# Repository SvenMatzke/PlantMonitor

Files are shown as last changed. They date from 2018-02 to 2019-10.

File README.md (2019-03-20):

# PlantMonitor
Whats the goal an esp sending soil moisture temperature, humidity and light to an source in your network.
The source for now is fully functioning webserver backend and a webfrontend written in react.

# ESP setup:
For all wireing we need wires so always keep in mind you will need those in addition to your chips and power. 

# Catch 
Easy plant monitoring in a few steps. 

# Setup
An Esp32 is the base as a controller for micropython. 
Simply because we have plenty of IO and plenty of power for little money and we can measure the 
Analog in even without resistors! On Esp8266 we would need a voltage between 0-1 V

## Additional Sensor
 - dht22 (AM2302) 
 - BH1750FVI GY-30
 - Soil Moisture Sensor
 
# for Comport
 - Reset Switch/Button

# Hardware (Power supply Part)
For the Power supply part we use simple AA Rechargeable batteries and a step up chip to get our needed 3.3 V
In the future it is planed that the power and sensor part are seperate in design. Because there are multiple solutions for 
powering up an esp and less variants regarding getting the sensor data we want.
  - 2 AA recharable batteries
  - 1 Booster step-up to 3.3 V (4,49 €)
    https://eckstein-shop.de/Pololu-33V-Step-Up-Spannungsregler-U1V10F3
  - battery holder or
  - Romi Battery Contact Set (2 € for 2 sets) 
 
costs without batteries 7€

# First Installation
Install micropython on your esp8266 (instructions in the micropython link below)
A fully functioning esp firmware can be found under the source folder.
This firmware is needed because if you dont precompile the userv.py and some the sensor module for the light sensor Tsl,
your esp will run out of memory and will not work.

# Second step 
Wire your sensors there is a folder wireing for more details or adjust the sensor.py with your own configuration.
Im the source folder is dist folder which will provide several data from the subfolder python and static_index/dist.
You will need to upload all there files, its the backend, and the webfrontend.

# Third step
Fire up your esp8266. When booting on hardreset you will have 300s to configure your
Plantmonitor via Web. Simply connect to the Wlan 'Plantmonitor' PW: 'Plantmonitor' 
and set the features you need like new ssid and password ;-).

# Running and be happy
From here your Esp will go to Deepsleep for a time set by your config. After this time it will wake up store the current 
sensor data and go offline again for your Deepsleep. To get your data either send them directly to another ip on fireup or
press the reset button to go into configuration-mode again. In this mode you are also able to
read all data saved by your esp yet. 
A webfrontend is reachable if you are connected directly under 192.168.1.4 else the ip used in your network.

# From here on out
We will want to pack power supply and apply your wireing and esp into an casing. 
An 3d printer example will be put in 3d casing

# Infos and Greetings
micropython:
https://docs.micropython.org/en/latest/esp8266/esp8266/tutorial/intro.html

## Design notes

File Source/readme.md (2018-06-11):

#link wireing todo

Frontend of Plantmonitor is static website with backend communication to the esp

Intention will be a webpacked javascript framework delivering everything we need even without internet.

we have 4 mb flash drive but there is also micropython and your python source on it.
this results in your webpacked static files should be less then 3 mb.
"""

Booting will just decide which wlan connection we will choose

http://docs.micropython.org/en/latest/esp8266/esp8266/tutorial/network_basics.html
http://docs.micropython.org/en/latest/esp8266/esp8266/tutorial/powerctrl.html

"""

Puts your device to deepsleep for a given time.
Hardware note:
connect gpio16 to reset to be able to deep sleep

"""
This will be the only file which may need to be customised
http://docs.micropython.org/en/latest/esp8266/esp8266/tutorial/dht.html
https://github.com/adafruit/micropython-adafruit-tsl2561/blob/master/docs/tsl2561.rst

"""

we need to but userv.py and the tsl2561 package into the build of the esp firmware because we dont have the memory to do it on the fly

https://pypi.python.org/pypi/tsl2561/3.3

sda=2 scl=14 
adc lower 1 v

unpowering light sensor_connection renders sensor useless so you cant unpower it

when starting server you need little above 9 k memory to run esp
# 

# Building firmware with needed external packages
Build your firmware with modules from from source/externalpackages
Normaly one firmware is checked in with the needed modules, but it is not sure that
this will stay this way. 

# Building Frontend
Step into folder source/static_index and follow the instructions. 

# Software assemble 
The main purpose is to assemble all needed files for one Device to flash.
Needed Software is:
    - builded micropython firmware 
    - builded frontendfiles

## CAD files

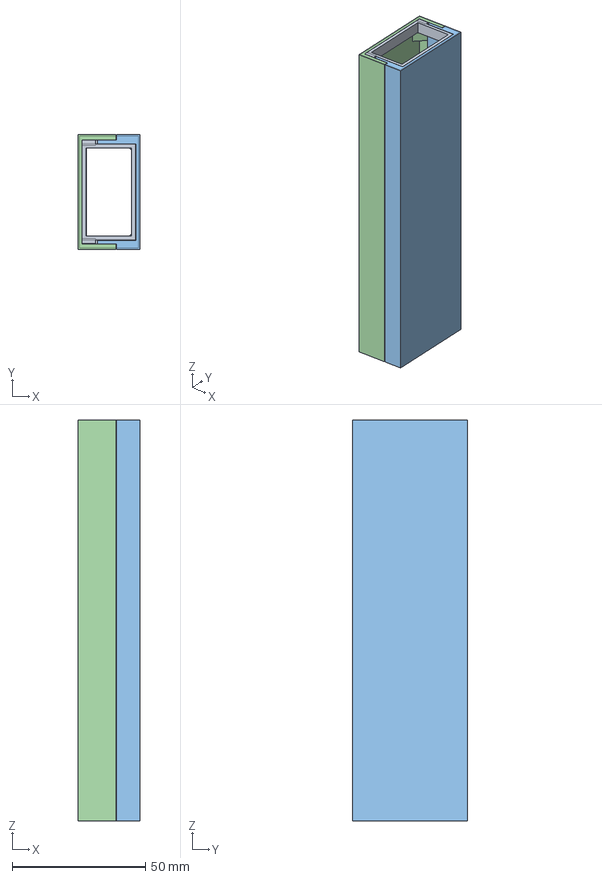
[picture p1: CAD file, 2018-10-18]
Assembly/BaseParts/assembly.FCStd
23.2 x 43.1 x 150.3 mm
BaseLowerSensorMount_01
BaseUpperSensorMount_01
BaseClippedSide_01
BaseClippingSide_01

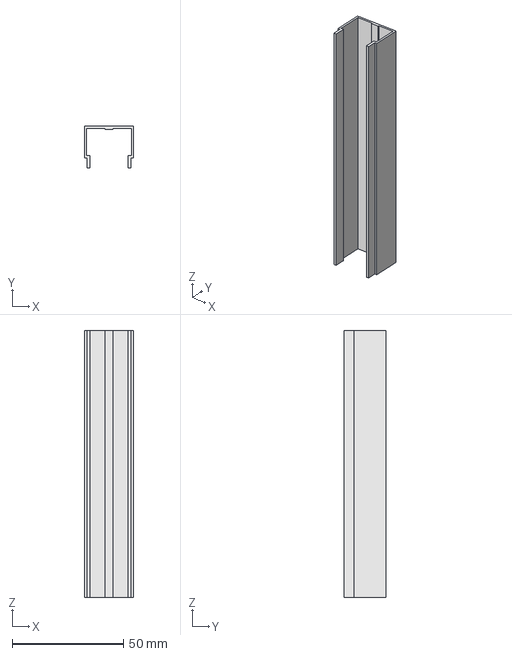
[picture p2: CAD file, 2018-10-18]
Assembly/BaseParts/BaseLeftSide.FCStd
22.0 x 18.7 x 120.0 mm

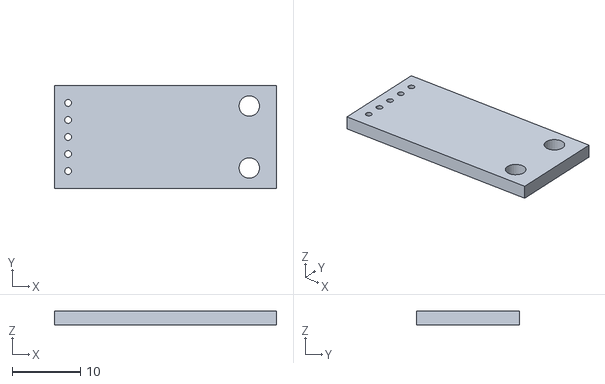
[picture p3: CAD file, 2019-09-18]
Assembly/ElectronicShapes/gy-30.stl
32.6 x 15.1 x 2.00

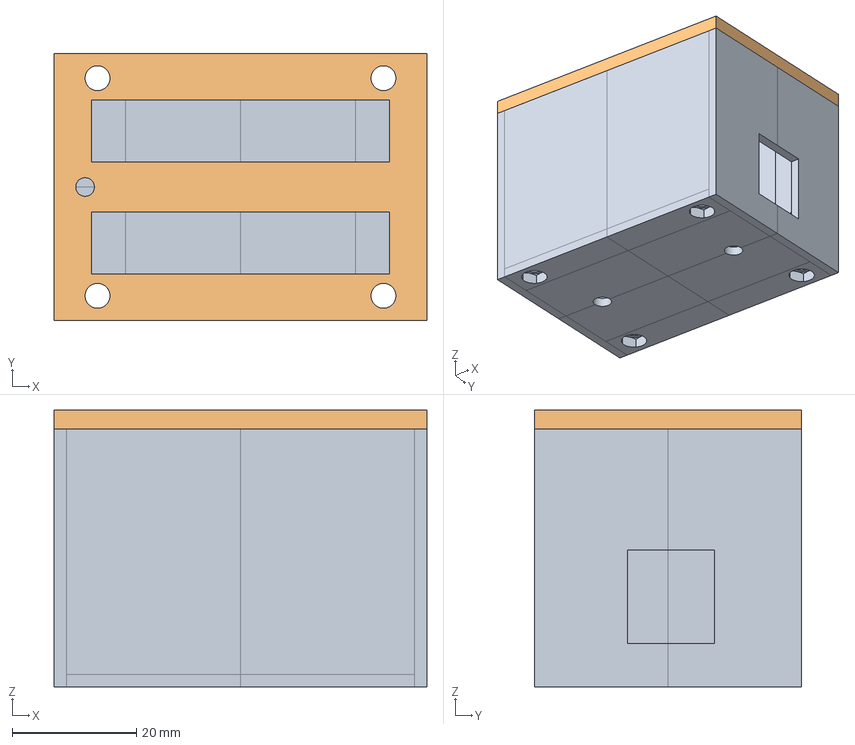
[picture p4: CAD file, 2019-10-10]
Assembly/GrownCubeSensor/esp32_box.FCStd
60.0 x 43.0 x 44.5 mm

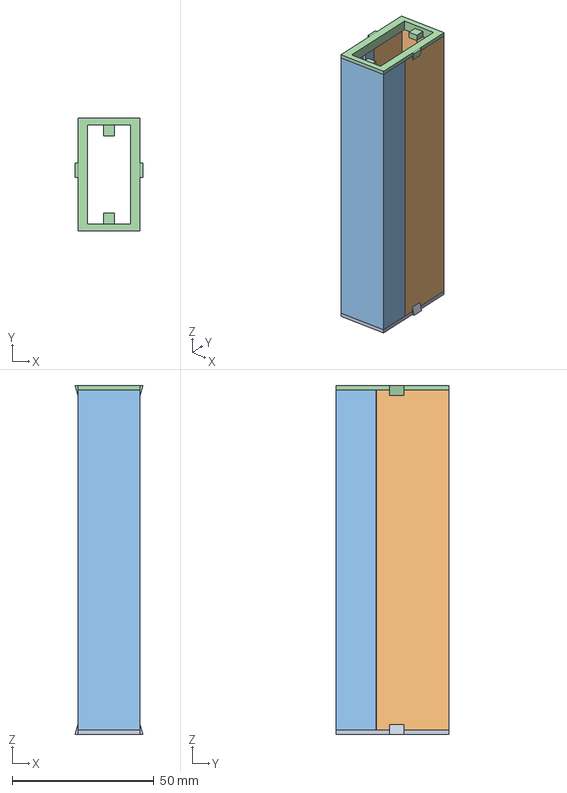
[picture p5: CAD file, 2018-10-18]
Assembly/test.FCStd
24.0 x 40.0 x 123.0 mm
BaseSensorMount_01
BaseRightSide_01
BaseLeftSide_01
BaseSensorMount_02

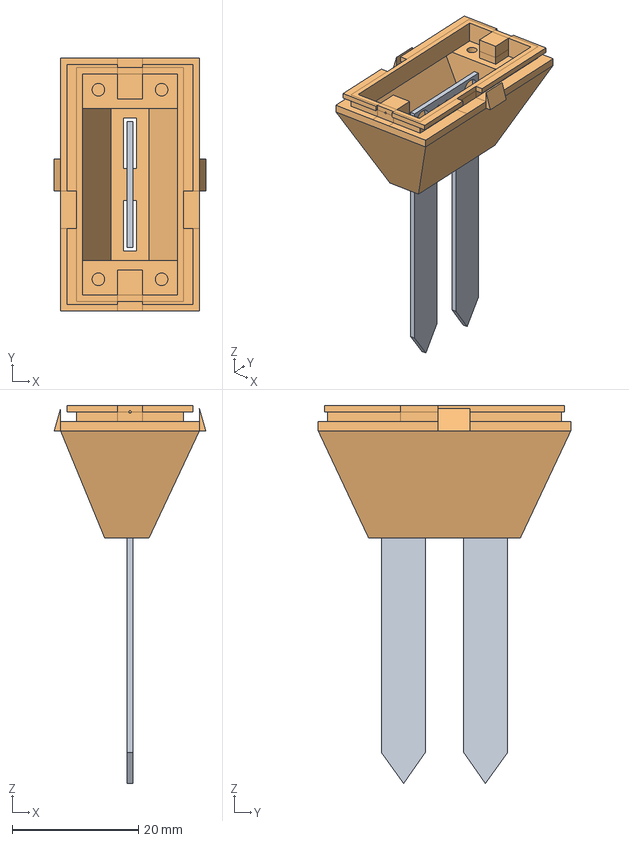
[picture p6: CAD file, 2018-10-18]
Assembly/version1/moisture_sensor.FCStd
24.0 x 40.0 x 59.8 mm
MoistureSensor_01
MountWithCutsAndHoles

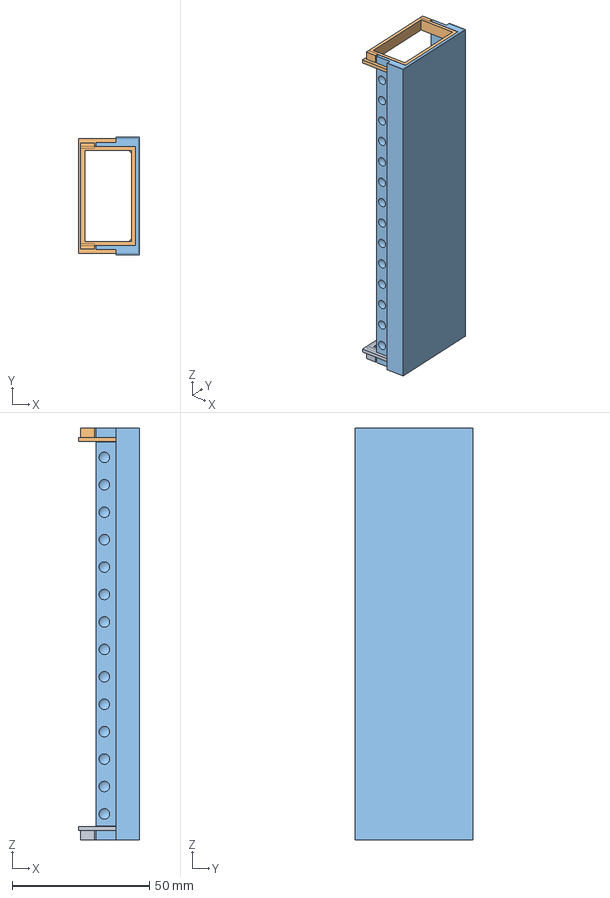
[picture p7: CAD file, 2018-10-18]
Assembly/BaseParts/NewBaseSensorMount.FCStd
22.4 x 43.0 x 150.2 mm
BaseSensorUpperMount
BaseSensorLowerMount
ClippedSideWithNodholesStablelise

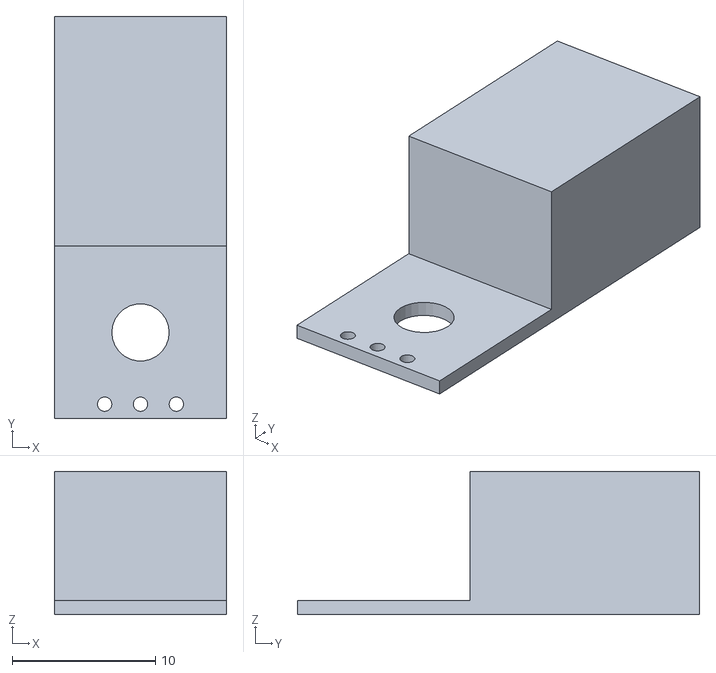
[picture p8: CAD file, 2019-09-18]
Assembly/ElectronicShapes/dht22.stl
12.0 x 28.0 x 10.0

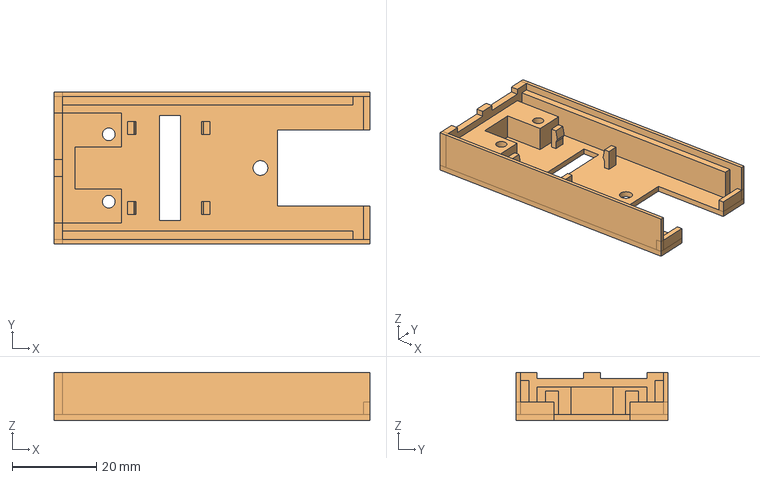
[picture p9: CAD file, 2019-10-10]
Assembly/GrownCubeSensor/CubeSensor.FCStd
75.0 x 36.0 x 11.5 mm
pcb_holder
Side1WithHoles

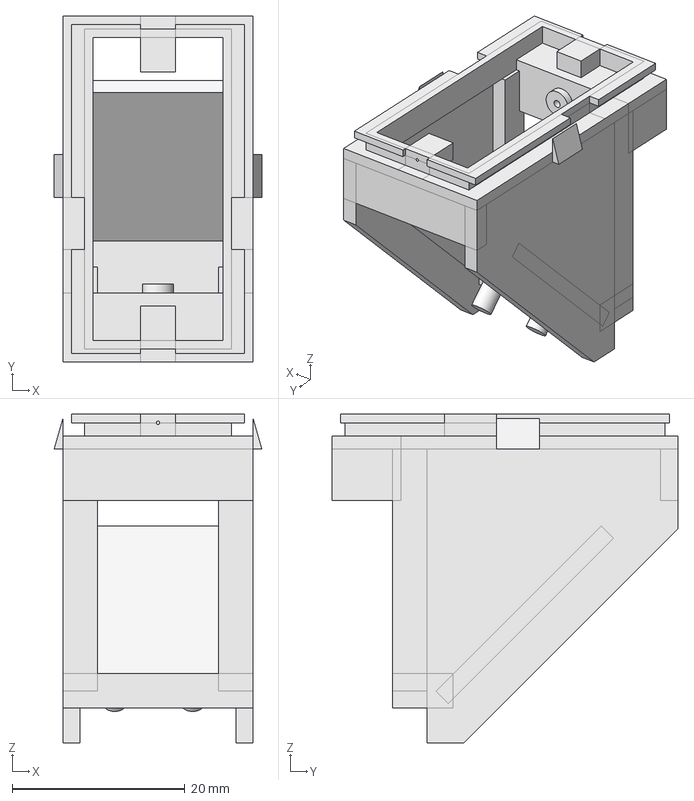
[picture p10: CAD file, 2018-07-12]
Assembly/version1/dht22AndBH1750.FCStd
24.0 x 40.0 x 38.0 mm

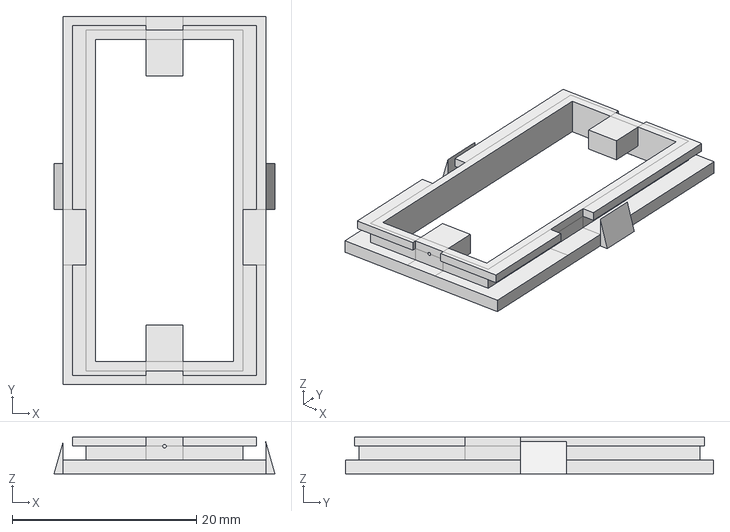
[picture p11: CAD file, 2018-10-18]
Assembly/BaseParts/BaseSensorMount.FCStd
24.0 x 40.0 x 4.01 mm

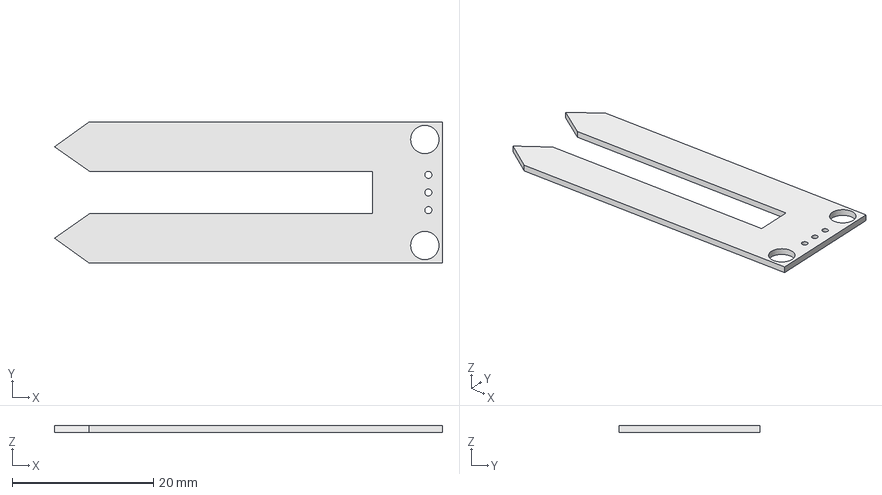
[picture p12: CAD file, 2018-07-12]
Assembly/ElectronicShapes/MoistureSensor.FCStd
54.9 x 20.0 x 1.00 mm

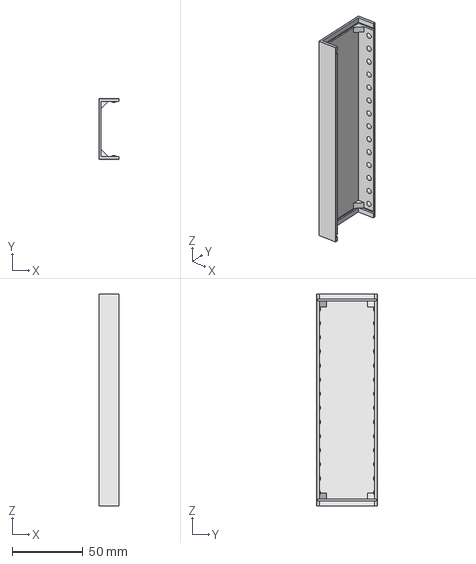
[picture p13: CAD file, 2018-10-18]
Assembly/BaseParts/BaseClippingSide.FCStd
14.2 x 43.0 x 150.2 mm

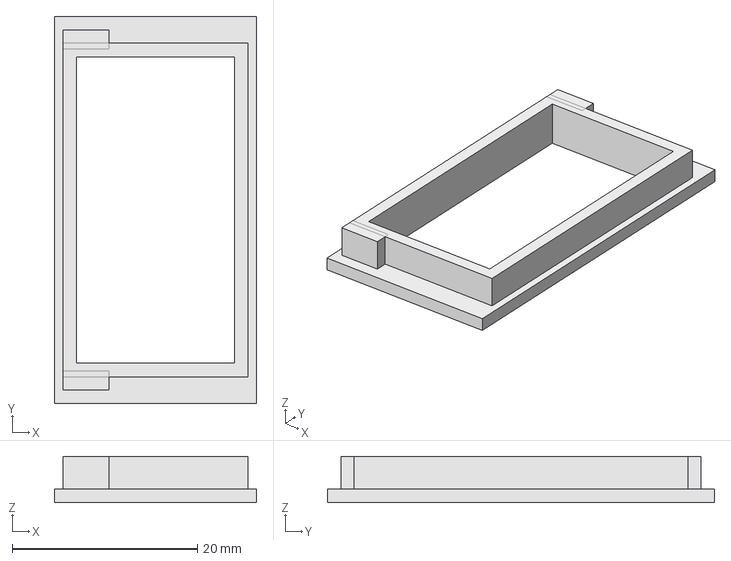
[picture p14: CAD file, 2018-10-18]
Assembly/BaseParts/BaseLowerSensorMount.FCStd
21.8 x 41.8 x 5.00 mm

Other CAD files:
Assembly/ElectronicShapes/Dht22Sensor.FCStd
Assembly/ElectronicShapes/BH1750FVI.FCStd
Assembly/BaseParts/BaseUpperSensorMount.FCStd
Assembly/BaseParts/BaseClippedSide.FCStd
Assembly/BaseParts/BaseRightSide.FCStd
Assembly/BaseParts/ESP8266_AiThinkerExpansionHolder.FCStd
Assembly/ElectronicShapes/moisture_sensor.stl

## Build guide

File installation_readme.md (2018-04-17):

# Install your device

First Step: \
install micropython.*.bin.

2nd Step:  
flash all python, javascript and html files.

3rd Step: \
Start your Device and push the reset button.
if you dont have a settings.json with login to your network. 
Which is normaly the case!
Connect to the Wireless Lan "Plantmonitor" Pw: "Plantmonitor".
When you are connected call https://192.168.1.4/ and configure your Esp.

4th Step: \
Be happy and have fun.

uploading files:
https://learn.adafruit.com/micropython-basics-load-files-and-run-code/install-ampy#upgrade-ampy

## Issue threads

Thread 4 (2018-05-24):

Modular Design for an casing

SvenMatzke, 2018-05-24:
Make a modular design were you can change certain parts to use different sensors or different power supply or even different microcontroller in the future.

SvenMatzke, 2018-06-05:
we will form a few base componentens which then will be used to as base to attach sensor components.
For the plant monitor for now we will add an dht22, an light sensor on the upper side. and the soil moisture sensor on the lower side. the hole component will first be designed to be tall and thin with around 4cm *2cm base and a height of 10 cm + sensor components.   As Power supply we will use 1 AA battery.  Which should give at least 1 month of power, but there is still alot of fine tuning.

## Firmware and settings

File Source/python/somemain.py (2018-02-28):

import gc
gc.collect()

buf = bytearray(2048)

import time
import urequests
import wlan
import userv
import sensor
import settings
import ujson
import machine
import ntptime

# get config data
loaded_settings = settings.get_settings()
# if anything fails we are ready to set up
restful_online_time = loaded_settings.get('awake_time_for_config', 300)
keep_alive_time = restful_online_time

if wlan.sta_if.active():
    # update time

    # wenn connected try to get new config if this fails we set restful_online_time
    # => this will result in more energy consumption, but else you can config this device
    request_url = loaded_settings.get("request_url", None)
    if request_url is not None:
        try:
            # send plant_monitor data
            sensor_data = sensor.sensor_data()
            sensor_data.update(loaded_settings.get('added_infos_to_sensor_data', {}))
            response = urequests.post(
                request_url,
                json=sensor_data
            )

            if int(response.status_code) >= 300:
                raise ConnectionError("Response was incorrect")

            keep_alive_time = loaded_settings.get('keep_alive_time_s')
            restful_online_time = loaded_settings.get('max_awake_time_s')
        except Exception as e:
            # data was not send so we will need some config changes
            restful_online_time = loaded_settings.get('awake_time_for_config', 300)

if machine.reset_cause() == machine.HARD_RESET:
    restful_online_time = 300  # config time will be hard set


# webserver will be started to listen
# Need to clean up some cache before its too low
print(gc.mem_free())

accumulated_time = 0
restful_online_time = 30
keep_alive_time = 10
start_time = time.time()

def shutdown_reached():
    return (time.time()-start_time) < 180
    global accumulated_time
    print("shutdown_active")
    while accumulated_time < restful_online_time:# and (time.time() - server.last_request_time) <= keep_alive_time:
        accumulated_time += int(keep_alive_time)
    print("loop closes")
    loop.stop()

# declare pages




plant_app = userv.App()


def _index(writer, request):
    return userv.static_file(writer, "index.html", buf)


def _static_js(writer, request):
    return userv.static_file(writer, "app.bundle.js", buf)


def _static_css(writer, request):
    return userv.static_file(writer, "styles.bundle.css", buf)


def _get_data(writer, request):
    sens_data = sensor.sensor_data()
    settings_data = settings.get_settings()
    sens_data.update(settings_data.get('added_infos_to_sensor_data', {}))
    return userv.json(writer, sens_data)


def _get_settings(writer, request):
    return userv.json(writer, settings.get_settings())


def _post_settings(writer, request):
    try:
        new_settings = ujson.loads(request.get('body'))
    except:
        return userv.json(writer, {"message": ""}, status=406)
    updated_settings = settings.save_settings(settings.get_settings(), new_settings)
    return userv.json(writer, updated_settings)


# routes
plant_app.add_route("/", _index, method='GET')
plant_app.add_route("/app.bundle.js", _static_js, method='GET')
plant_app.add_route("/styles.bundle.css", _static_css, method='GET')
plant_app.add_route("/data", _get_data, method='GET')
plant_app.add_route("/settings", _get_settings, method='GET')
plant_app.add_route("/settings", _post_settings, method='POST')



# run server
print(gc.mem_free())

plant_app.run_server(
    timeout_callback=shutdown_reached
)
print(gc.mem_free())

# deepsleep.set_awake_time_and_put_to_deepsleep(
#     loaded_settings.get("deepsleep_s", 100)
# )

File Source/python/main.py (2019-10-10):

try:
    from grown import setup, run_grown
    import webrepl
    import machine

    grown = setup()
    webrepl.start()
    print("reset %s: " % machine.reset_cause())
    if machine.reset_cause() in [machine.HARD_RESET, machine.PWRON_RESET]:
        import upip

        upip.install('grown')
        machine.reset()

    from grown.light_control import add_light_control
    from grown.data_control import add_data_control
    from bh import BH1750
except ImportError:
    import network
    import ujson

    file_ptr = open("settings_store.json", "r")
    store = ujson.loads(file_ptr.read())
    sta_if = network.WLAN(network.STA_IF)
    sta_if.active(True)
    sta_if.connect(store['wlan']['ssid'], store['wlan']['password'])
    import upip

    upip.install('grown')
    import machine

    machine.reset()

import requests
import ujson as json

import machine
import dht
import uasyncio as asyncio
import time


# light control
def _enable_light():
    current_state = json.loads(requests.get("http://192.168.2.106/report").content)
    relay_state = current_state.get('relay', True)
    if relay_state is False:
        requests.get('http://192.168.2.106/relay?state=1')


def _disable_light():
    current_state = json.loads(requests.get("http://192.168.2.106/report").content)
    relay_state = current_state.get('relay', True)
    if relay_state is True:
        requests.get('http://192.168.2.106/relay?state=0')


# sensor values
max_adc = 2350

pwr = machine.Pin(23, machine.Pin.OUT)
pwr2 = machine.Pin(18, machine.Pin.OUT)
i2c = machine.I2C(scl=machine.Pin(26), sda=machine.Pin(25))
adc = machine.ADC(machine.Pin(34))
adc.atten(machine.ADC.ATTN_11DB)
dht_sensor = dht.DHT22(machine.Pin(19))


def _convert_adc_to_precentage(adc_value):
    return adc_value * 100 / max_adc


async def get_sensor_data():
    values = {}
    print("Measure")
    try:
        pwr.on()
        pwr2.on()
        await asyncio.sleep(3)
        light = BH1750(i2c)
        dht_sensor.measure()
        await asyncio.sleep(1)
        values = {
            "moisture": _convert_adc_to_precentage(adc.read()),
            "lumen": light.luminance(0x20),
            "temperature": dht_sensor.temperature(),
            "humidity": dht_sensor.humidity()
        }
    except Exception as e:
        print("Failure in measure: %s " % str(e))
    finally:
        pwr.off()
        pwr2.off()
    return values


add_light_control(grown, _enable_light, _disable_light, lambda x: False)
add_data_control(grown, get_sensor_data)

run_grown()

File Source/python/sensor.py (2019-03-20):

import dht
import machine
import time
import tsl2561
import ujson
import os
import gc
import error

_adc = None
_dht = None
_light_sensor = None
_power = machine.Pin(13, machine.Pin.OUT)
_power.value(1)


def power_on():
    _power.value(1)


def power_off():
    _power.value(0)


try:
    _adc = machine.ADC(0)
except Exception:
    error.add_error("ADC is not defined")

try:
    _dht = dht.DHT22(machine.Pin(12))
except Exception:
    error.add_error("Dht22 is not running.")

try:
    _scl = machine.Pin(14)
    _sda = machine.Pin(2)
    _i2c = machine.I2C(scl=_scl, sda=_sda)
except Exception:
    error.add_error("Lightsensor is not running.")

_config_file = "sensor_config.json"
history_sensor_data_file = "sensor_data_log.json"
power_off()


def configure_sensor():
    """
    saves max sensor values for configuration
    :return: dict
    """
    power_on()
    time.sleep(1)
    try:
        config = {"adc_max": _adc.read()}
    except:
        power_off()
        return {"adc_max": 1024}
    finally:
        power_off()

    file_ptr = open(_config_file, "w")
    try:
        file_ptr.write(ujson.dumps(config))
    finally:
        file_ptr.close()
    return config


def _load_configuration():
    if _config_file in os.listdir():
        file_ptr = open(_config_file, "r")
        try:
            read_file = file_ptr.read()
            loaded_config = ujson.loads(read_file)
        except ValueError:
            os.remove(_config_file)
            loaded_config = {"abc_max": 1024}
        finally:
            file_ptr.close()
    else:
        loaded_config = configure_sensor()
    return loaded_config


_loaded_config = _load_configuration()


def _get_soil_moisture():
    """
    :return: returns the soil_moisture in percentage
    :rtype: tuple(key, int)
    """
    if _adc is None:
        return (("soil moisture", -1),)

    adc_max = _loaded_config.get("adc_max", 1024)
    adc_read = _adc.read() * 100
    return (("soil moisture", 100 - adc_read // adc_max),)


def _get_temperature_and_humidity():
    """
    :return: Returns temperature and humidity at the given pin
    :rtype: tuple[tuple]
    """
    if _dht is None:
        return ("temperature", -100), ("humidity", -1)

    _dht.measure()
    return ("temperature", _dht.temperature()), ("humidity", _dht.humidity())


def _get_light_measure():
    _light_sensor = tsl2561.TSL2561(_i2c, address=0x39)
    return (("light", _light_sensor.read()),)

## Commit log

2018-01-29 updated sensor now working need to fix main py and add picoweb next
    [boot.py, sensor.py]
2018-02-15 fixing a lot memory still not there yet
    [boot.py, main.py, requests.py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]
2018-02-25 fixed a lot still serving js css and html at the some time seems to be a problem with 1 socket so far
    [boot.py, requests.py, sensor.py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]
2018-02-28 basic functions work now we need to bugfix interface and further implement sensor_data history and adc convert
    [main.py, sensor.py]
2018-03-01 bugfix userv on false call
    [userv.py]
2018-03-01 fixing ujson dumps and adc sensor now returns percentage
    [main.py, sensor.py]
2018-03-01 Hard reset now triggers creating new network
    [boot.py]
2018-03-05 updated sensor_saving but still need to shutdown sensor
2018-03-07 sensors are only online when needed. main.py now adds history data of sensors
2018-03-21 changed main py for power usage there was a bug or rather default was 180 s online time if no url configured. in the future getting the result will be triggered by using a reset so a longer config wi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
    [boot.py, main.py]
2018-03-22 start changing to material ui
2018-03-28 added error log dht sometimes failes needs to be online whole time. app remodeled on material design
    [main.py, sensor.py]
2018-04-03 sensor data now wait till all data is collectable main.py was too big so we splitted server into a new file
    cleaned up App and start a mock server for development of frontend
    [main.py, sensor.py]
2018-04-04 bigger change current there were only 470 reads with 2 aa batteries. because network connect and setting up takes 50 seconds even if server is only online for 20 seconds the offset is too much. => we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
    [boot.py, main.py, sensor.py]
2018-04-04 batches could get too huge and hard reset should always start webserver which was not the case
    [boot.py]
2018-04-11 added graph to js hope file is now not too big else fixing sensor_history
2018-04-12 fixed history data content_len added maximum sensor_Data_log size
    [sensor.py]
2018-04-16 changed some sensor.py connection so that broken sensors do not fail the whole system
    [boot.py, sensor.py]
2018-04-23 added power_switch back to sensor.py and optimised buffer for server to 4000 still around 9k free memory
2018-06-11 first Cad drafts still need practice alot
    [BH1750FVI.FCStd, BaseLeftSide.FCStd, BaseRightSide.FCStd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]
2018-06-12 moving parts to work better with the assembly
    [BH1750FVI.FCStd, BaseLeftSide.FCStd, BaseRightSide.FCStd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]
2018-07-12 first version only needs the sides but before i print mounts and see if all works out
    [BaseLeftSide.FCStd, BaseRightSide.FCStd, MoistureSensor.FCStd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]
2018-10-18 second attempt slowly getting there
    [BaseClippedSide.FCStd, BaseClippingSide.FCStd, BaseLeftSide.FCStd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]
2019-09-18 cube case v1
    [CubeSensor.FCStd]
2019-10-10 move of html to cdn package
    [CubeSensor.FCStd, esp32_box.FCStd]
